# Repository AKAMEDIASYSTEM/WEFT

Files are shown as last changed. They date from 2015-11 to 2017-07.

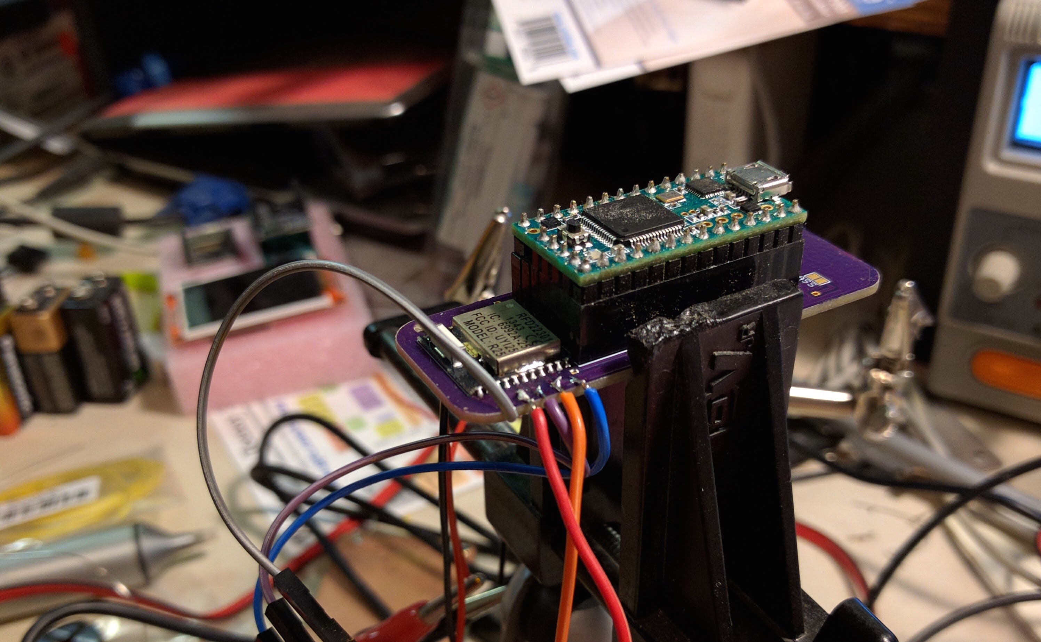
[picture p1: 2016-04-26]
WEFT-photos/electrovibration-experiments4.jpg

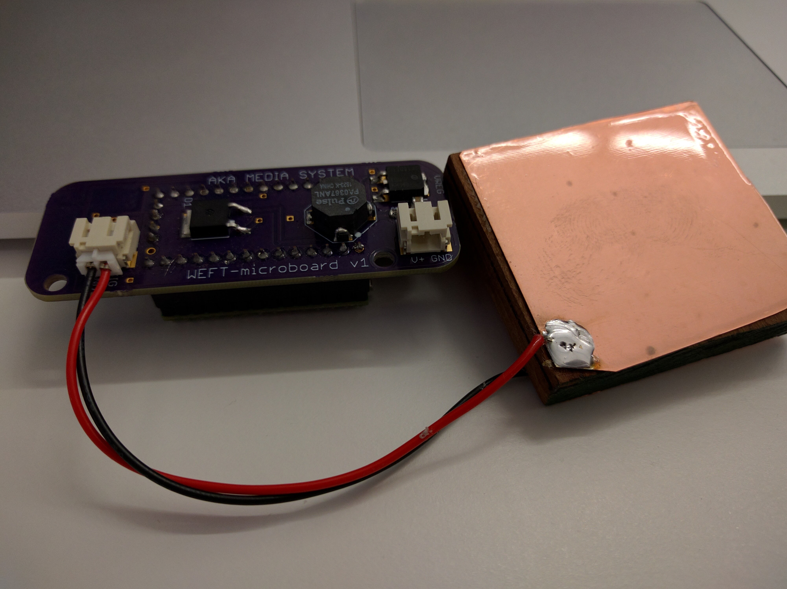
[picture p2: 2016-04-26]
WEFT-photos/electrovibration-experiments5.jpg

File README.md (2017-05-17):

# WEFT
#### Experiments in electrovibration interaction strategies, inspired by Disney Research papers "Tesla Touch" and "Revel"

Here are the papers I am trying to implement here:
http://www.ivanpoupyrev.com/e-library/2010/teslatouchUIST2010.pdf

http://www.disneyresearch.com/wp-content/uploads/REVEL.pdf

### Summary
Basically, the papers describe a way to augment surfaces with _dynamically changeable tactile properties_ - a surface can change from sticky to slippery basically at will.

### Status
This work is incomplete and ongoing - for one thing, while the circuit decribed here works, I have yet to implement current-sensing feedback as described in the papers. I'm eager to accomplish this because it allows normalization of sensation across people, skin moistures, and time.

### Why I am interested
I'm interested in experimenting with this technology as applied to various notification strategies, particularly on mobile and wearable devices.
I would like to develop interactions in which a person queries a "stack" of stuff waiting for them, rather than being interrupted by a push notification.
The appeal of this technology in this application is that it's totally silent and able to be done without interrupting the person's conversation by stealing focus.
If this technology is implemented on the back of a mobile device, for example, simply rubbing a finger along the back of the phone is all that is needed to see the magnitude of my "stack."
Of course, "stack" can be many things: number of unread emails, number of to-do items, number of places of interest very near me, and so on.

### This repository
The purpose of this repo is to make my work shareable - I had a fair amount of trouble trying to go from the research paper to a safe, working circuit, and I'm hoping to save others some work.

The circuitboard isn't what I would put onto a phone - it is instead a platform for trying out different waveforms, intensities, and so on.

The intent is that you will use the board to figure out the correct implementation details and then generate your own board with a more appropriate layout.

### Requirements
You should follow the BOM pretty precisely unless you know what you are doing. The circuit is designed to work with a 9v battery and I will be trying to allow smaller/more power supplies to work with it. The microcontroller is a Teensy 3.1

### Thanks
I'm so grateful to Disney Research, Ivan Poupyrev, Olivier Bau, and others who worked on the papers for making their work available - I never would have known aobut this cool phoneomenon without their shared work! Thanks as well to nytlabs for supporting my explorations and letting me share in kind.

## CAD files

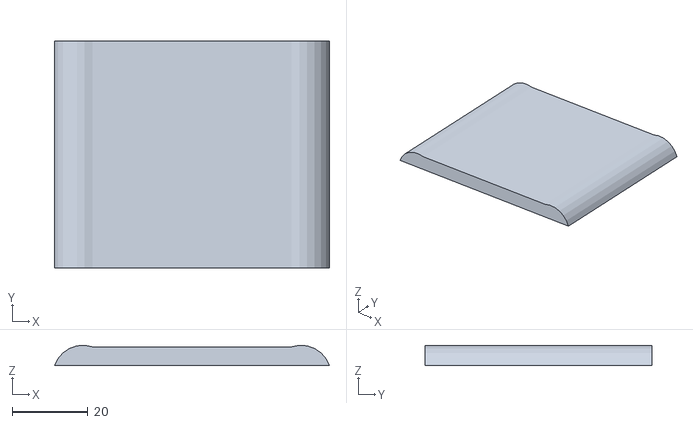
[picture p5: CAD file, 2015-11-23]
CAD/WEFT-form-test-0.stl
72.8 x 60.0 x 5.39

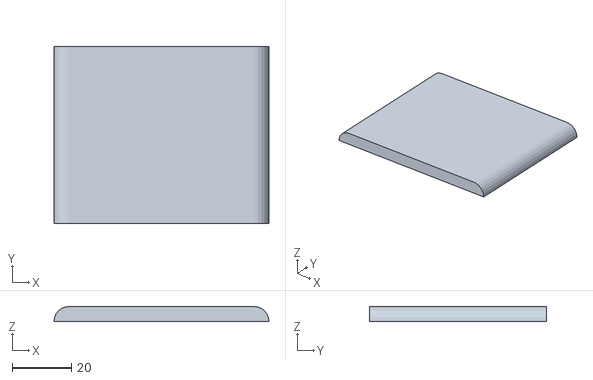
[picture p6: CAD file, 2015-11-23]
CAD/WEFT-form-test-0nobump.stl
72.8 x 60.0 x 5.00

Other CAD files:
CAD/WEFT-form-test-0.skp
CAD/WEFT-form-test-0nobump.skp
CAD/WEFT-form-test-0nobump~.skp
CAD/WEFT-form-test-0~.skp

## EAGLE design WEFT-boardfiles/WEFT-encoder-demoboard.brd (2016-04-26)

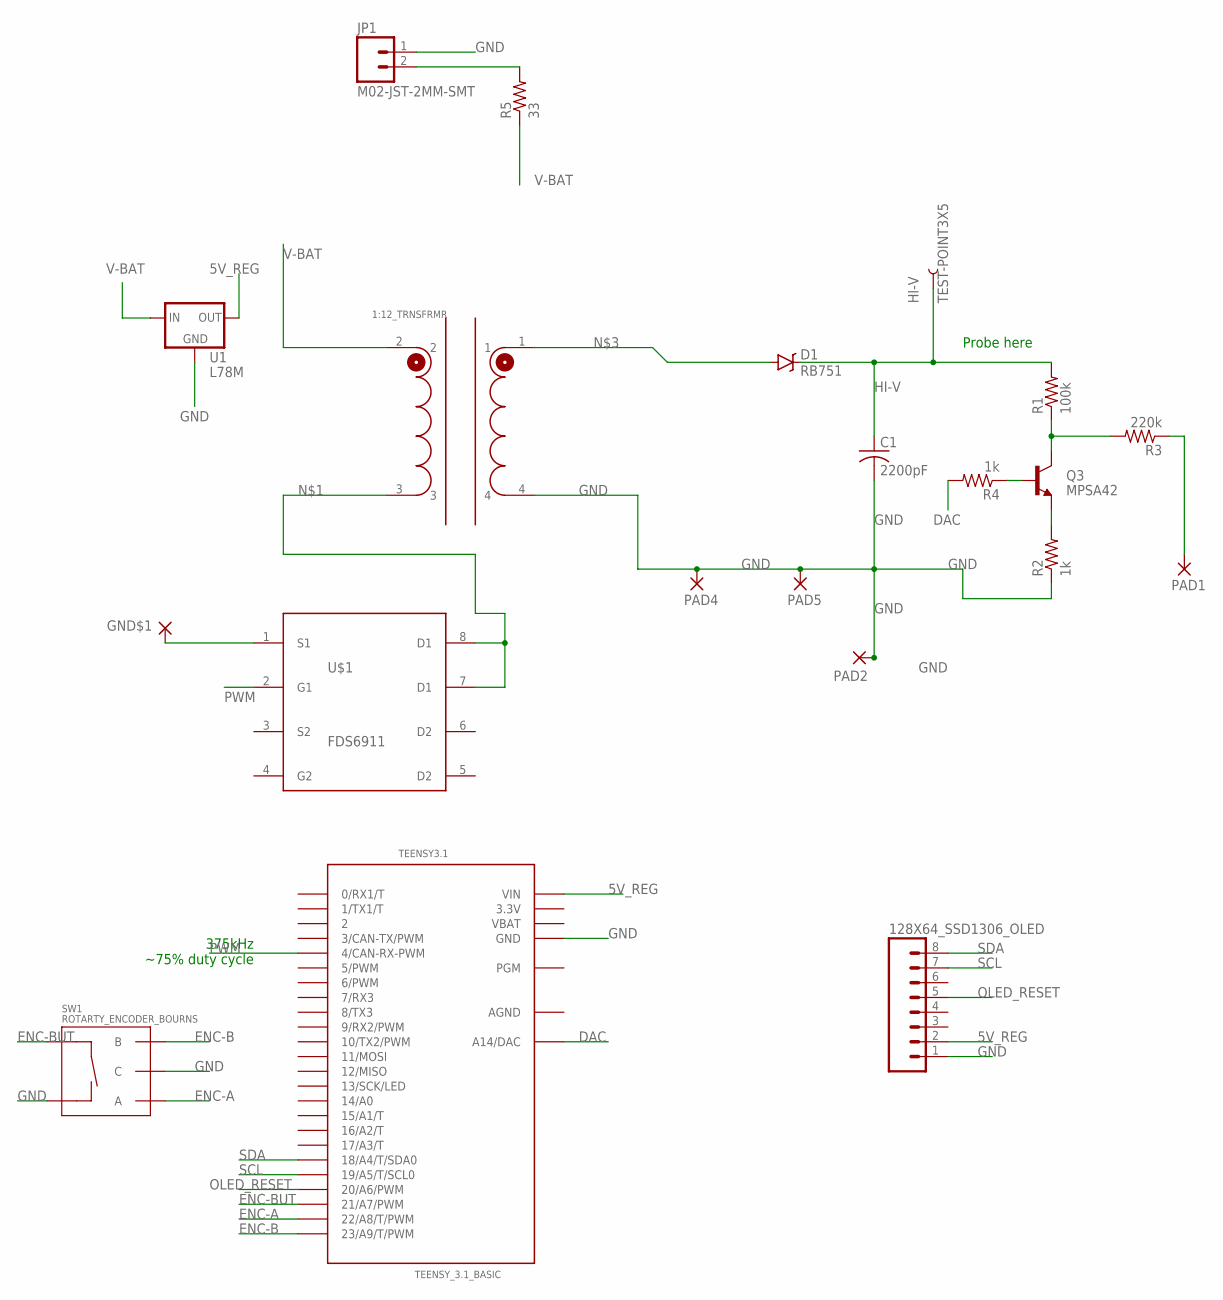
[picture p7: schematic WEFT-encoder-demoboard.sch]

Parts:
1:12_TRNSFRMR: PA0367
128X64_SSD1306_OLED: M08LOCK; 1X08_LOCK
C1: 2200pF; C1812
D1: RB751; TO263
GND$1: WIREPADSMD5-2,5; 5-2,5
HI-V: TEST-POINT3X5; PAD.03X.05
JP1: M02-JST-2MM-SMT; JST-2-SMD
PAD1, PAD2, PAD4, PAD5: WIREPADSMD5-2,5; 5-2,5
Q3: MPSA42; TO-92
R1: 100k; R2010
R2, R4: 1k; 1206
R3: 220k; R2010
R5: 33; 1206
SW1: ROTARTY_ENCODER_BOURNS; ROTARY_ENC_PLAIN_BOURNS
TEENSY3.1: TEENSY_3.1_BASIC
U1: L78M; DPAK
U$1: FDS6911; SO8

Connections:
3.3V: TEENSY3.1.3.3V
5V_REG: 128X64_SSD1306_OLED.2, TEENSY3.1.VIN, U1.3 (OUT)
AGND: TEENSY3.1.AGND
DAC: R4.2, TEENSY3.1.A14 (A14/DAC)
ENC-A: SW1.A, TEENSY3.1.22/A8 (22/A8/T/PWM)
ENC-B: SW1.B, TEENSY3.1.23/A9 (23/A9/T/PWM)
ENC-BUT: SW1.SW+, TEENSY3.1.21/A7 (21/A7/PWM)
GND: 1:12_TRNSFRMR.4, 128X64_SSD1306_OLED.1, C1.2, GND$1.1, JP1.1 (2), PAD2.1, PAD4.1, PAD5.1, R2.1, SW1.C, SW1.SW-, TEENSY3.1.GND, TEENSY3.1.GND1 (GND), U1.4 (GND), U$1.1 (S1)
HI-V: C1.1, D1.1 (C), HI-V.P$1, R1.2
unnamed: 1:12_TRNSFRMR.3, U$1.7 (D1), U$1.8 (D1)
unnamed: 1:12_TRNSFRMR.1, D1.2 (A)
unnamed: JP1.2 (1), R5.2
unnamed: Q3.1 (C), R1.1, R3.2
unnamed: Q3.3 (E), R2.2
unnamed: Q3.2 (B), R4.1
OLED_RESET: 128X64_SSD1306_OLED.5, TEENSY3.1.20/A6 (20/A6/PWM)
PAD: PAD1.1, R3.1
PWM: TEENSY3.1.4 (4/CAN-RX-PWM), U$1.2 (G1)
SCL: 128X64_SSD1306_OLED.7, TEENSY3.1.19/A5 (19/A5/T/SCL0)
SDA: 128X64_SSD1306_OLED.8, TEENSY3.1.18/A4 (18/A4/T/SDA0)
V-BAT: 1:12_TRNSFRMR.2, R5.1, U1.1 (IN)
VBAT: TEENSY3.1.VBAT

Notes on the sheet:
Probe here
375kHz ~75% duty cycle

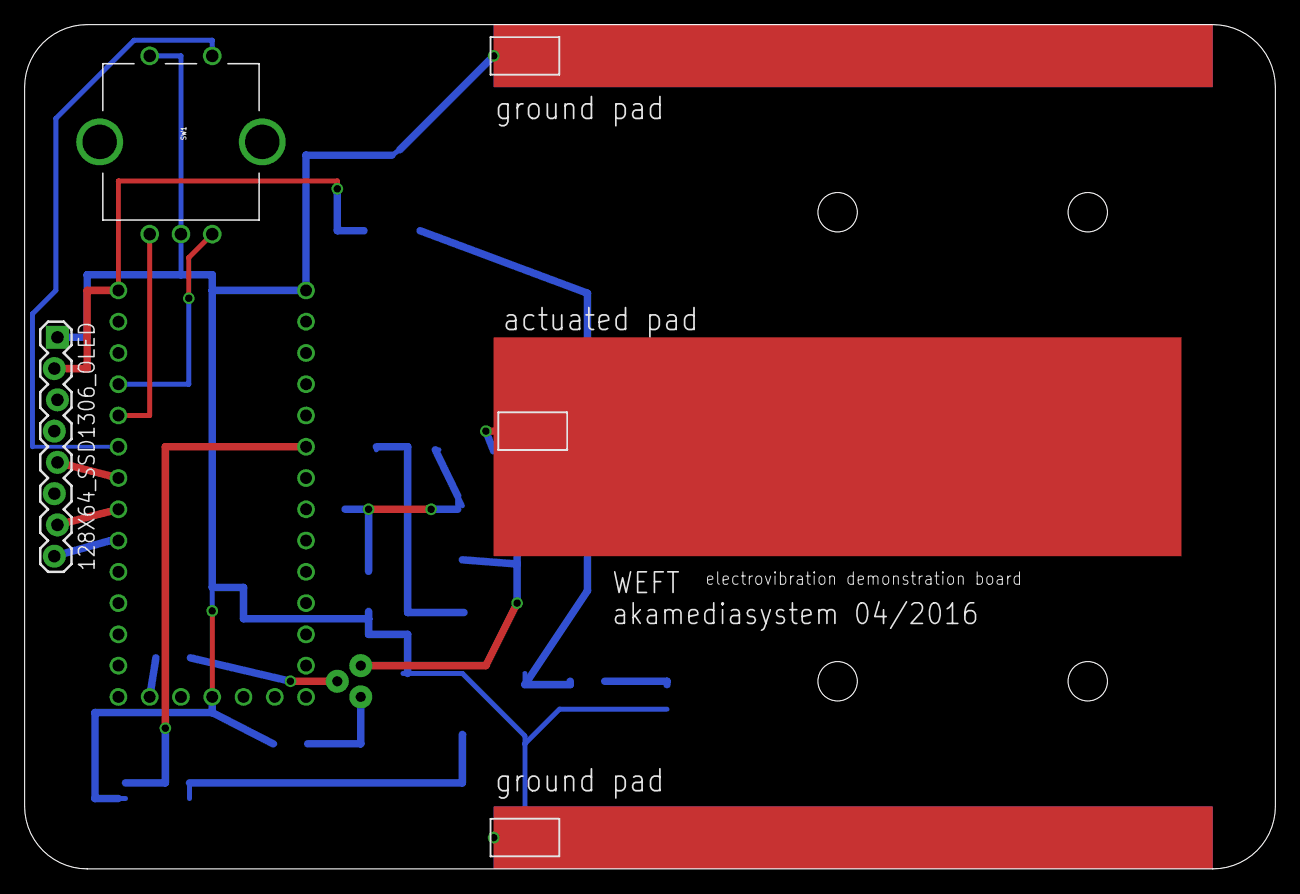
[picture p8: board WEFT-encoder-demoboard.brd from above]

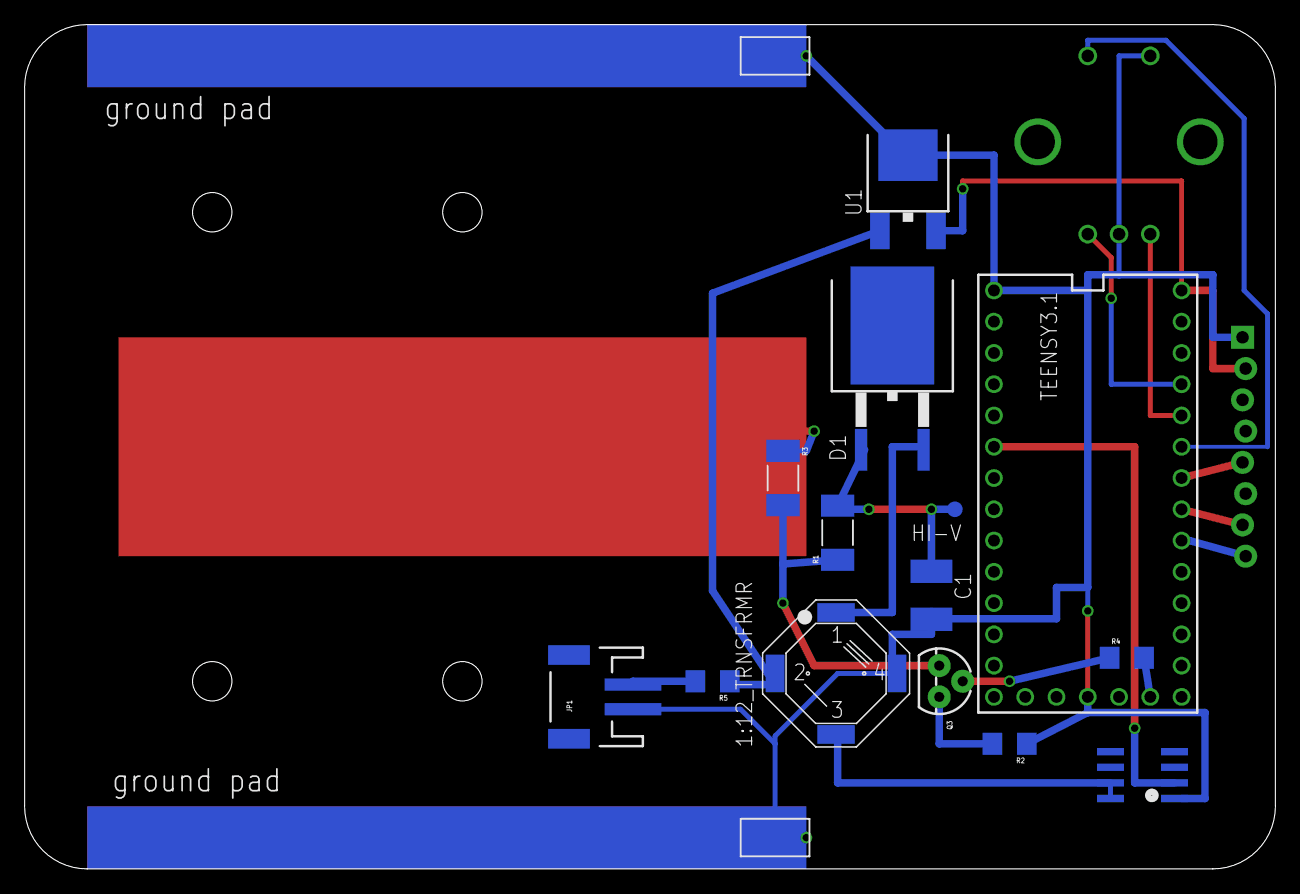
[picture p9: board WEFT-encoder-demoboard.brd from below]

Board: 2 copper layers, 101.6 x 68.6 mm, 21 parts (16 on the bottom side), 19 nets.

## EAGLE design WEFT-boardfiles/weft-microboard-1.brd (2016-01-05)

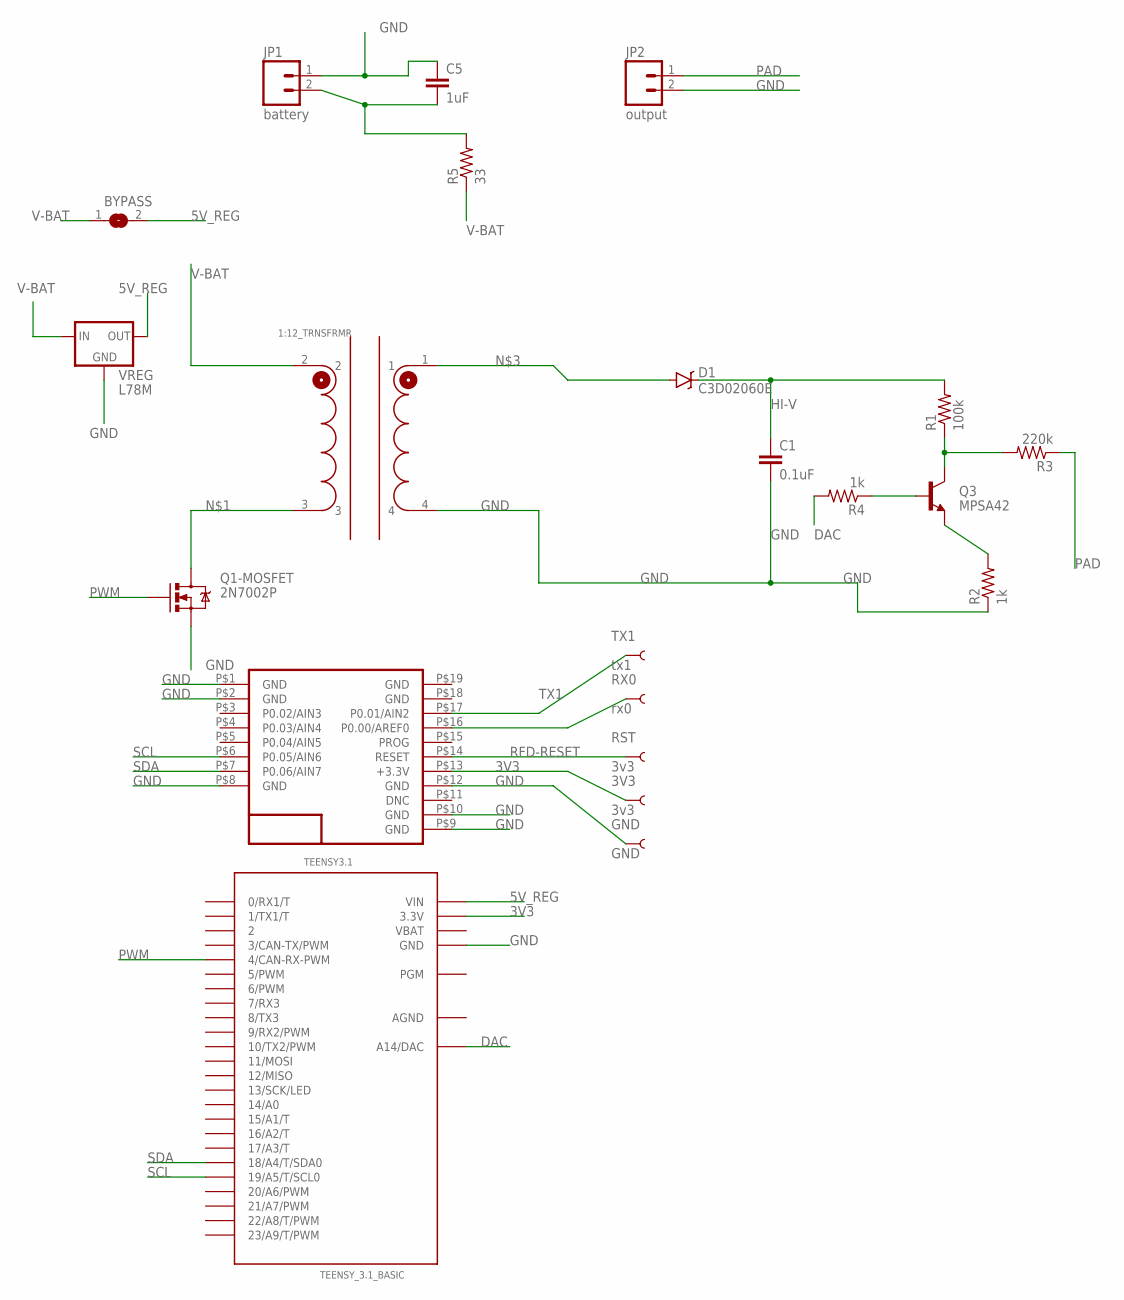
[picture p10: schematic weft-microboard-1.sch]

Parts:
1:12_TRNSFRMR: PA0367
3V3: 3v3; PAD.03X.03
BYPASS: SJ
C1: 0.1uF; 0805
C5: 1uF; 0805
D1: C3D02060E; TO252
GND: GND; PAD.03X.03
JP1: battery; JST-2-SMD
JP2: output; JST-2-SMD
Q1-MOSFET: 2N7002P; SOT23-3
Q3: MPSA42; SOT23-3
R1: 100k; 1206
R2, R4: 1k; 0805
R3: 220k; 1206
R5: 33; 0805
RFDUINO: RFD22301; RFD21733
RST: 3v3; PAD.03X.03
RX0: rx0; PAD.03X.03
TEENSY3.1: TEENSY_3.1_BASIC
TX1: tx1; PAD.03X.03
VREG: L78M; DPAK

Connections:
3V3: 3V3.P$1, RFDUINO.P$13 (+3.3V), TEENSY3.1.3.3V, TEENSY3.1.3.3V1 (3.3V)
5V_REG: BYPASS.2, TEENSY3.1.VIN, VREG.3 (OUT)
AGND: TEENSY3.1.AGND
DAC: R4.2, TEENSY3.1.A14 (A14/DAC)
EMIT: Q3.2 (E), R2.2
GND: 1:12_TRNSFRMR.4, C1.2, C5.1, GND.P$1, JP1.1 (2), JP2.2 (1), Q1-MOSFET.2 (S), R2.1, RFDUINO.P$1 (GND), RFDUINO.P$2 (GND), RFDUINO.P$8 (GND), RFDUINO.P$9 (GND), RFDUINO.P$10 (GND), RFDUINO.P$12 (GND), TEENSY3.1.GND, TEENSY3.1.GND1 (GND), VREG.4 (GND)
HI-V: C1.1, D1.1 (C), R1.2
unnamed: 1:12_TRNSFRMR.3, Q1-MOSFET.3 (D)
unnamed: RFDUINO.P$16 (P0.00/AREF0), RX0.P$1
unnamed: 1:12_TRNSFRMR.1, D1.2 (A)
unnamed: C5.2, JP1.2 (1), R5.2
unnamed: Q3.3 (C), R1.1, R3.2
unnamed: Q3.1 (B), R4.1
PAD: JP2.1 (2), R3.1
PWM: Q1-MOSFET.1 (G), TEENSY3.1.4 (4/CAN-RX-PWM)
RFD-RESET: RFDUINO.P$14 (RESET), RST.P$1
SCL: RFDUINO.P$6 (P0.05/AIN6), TEENSY3.1.19/A5 (19/A5/T/SCL0)
SDA: RFDUINO.P$7 (P0.06/AIN7), TEENSY3.1.18/A4 (18/A4/T/SDA0)
TX1: RFDUINO.P$17 (P0.01/AIN2), TX1.P$1
V-BAT: 1:12_TRNSFRMR.2, BYPASS.1, R5.1, VREG.1 (IN)
VBAT: TEENSY3.1.VBAT

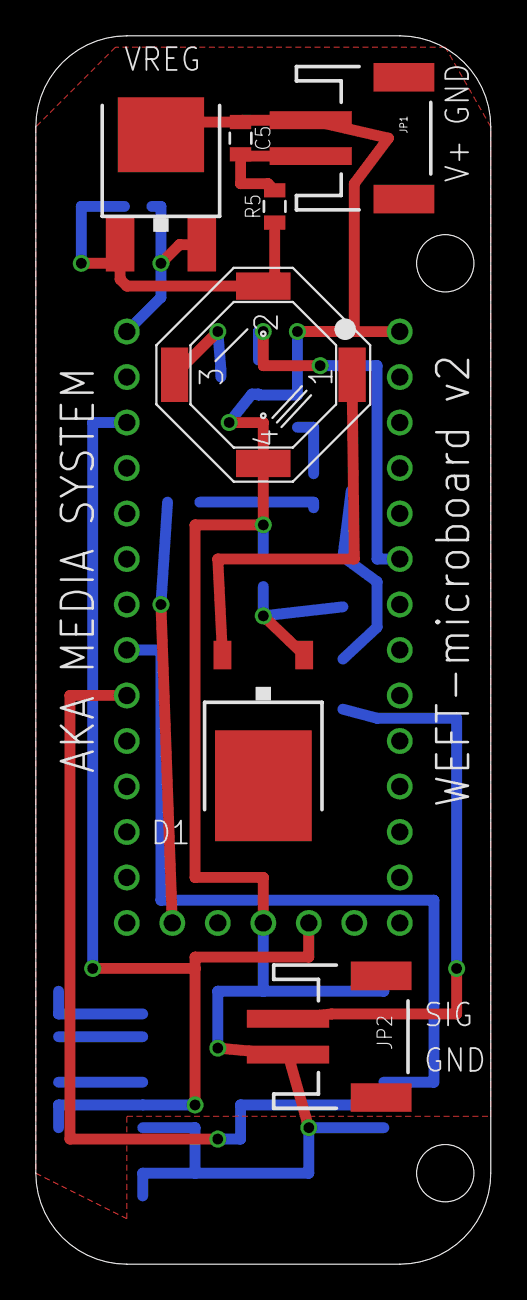
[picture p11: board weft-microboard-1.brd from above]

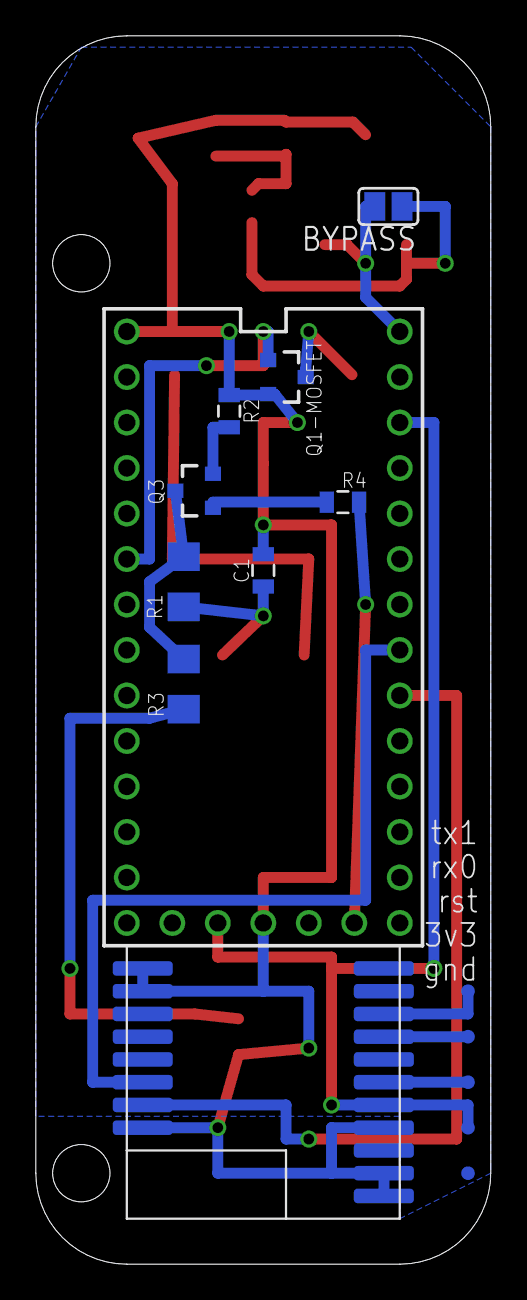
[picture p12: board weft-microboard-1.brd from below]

Board: 2 copper layers, 25.4 x 68.6 mm, 22 parts (15 on the bottom side), 19 nets.

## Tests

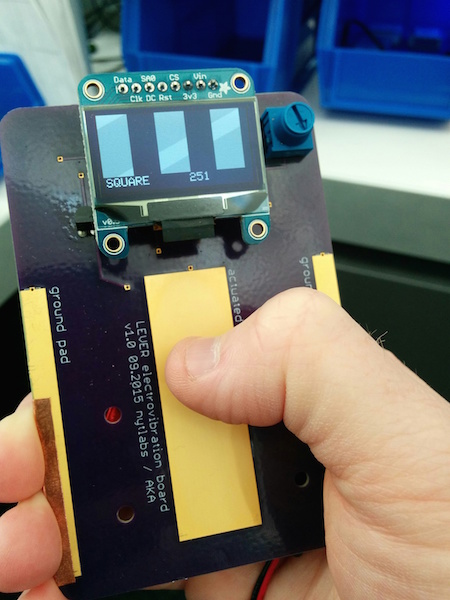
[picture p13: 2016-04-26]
WEFT-photos/electrovibration-experiments1.jpg

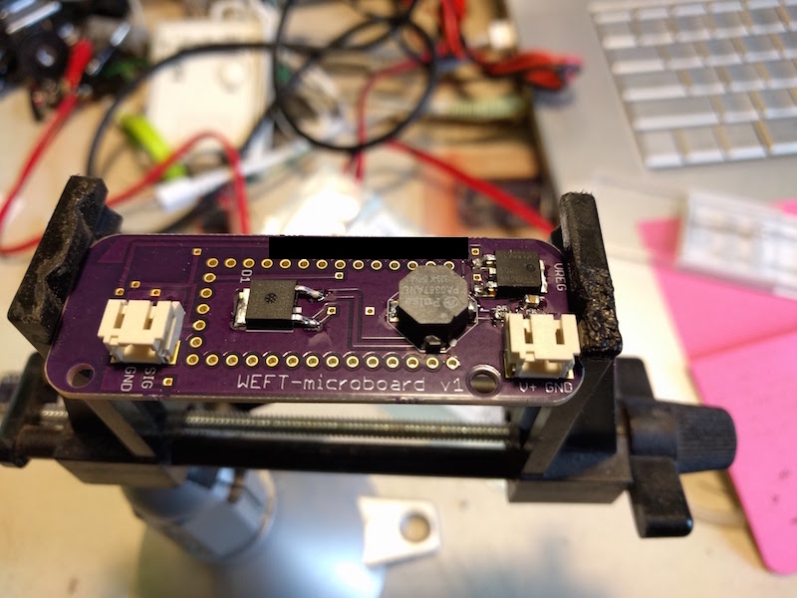
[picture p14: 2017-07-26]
WEFT-photos/electrovibration-experiments2.jpg

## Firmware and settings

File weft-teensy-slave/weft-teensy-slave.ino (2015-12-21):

// 
/*
// WEFT driver for implementation of REVEL and TeslaTouch papers by Disney Research
// for teensy 3.1
// Digital pin 4 sends hi-freq PWM (altered to send at 375kHz) to a boost converter circuit
// Analog pin 14 (it's a real DAC on the teensy 3.1) sends variable-freq sine wave to a hi-voltage transistor circuit
// that modulates the boosted supply voltage
// freqPot on pin A7 sets the signal frequency
// SDA on pin A4
// SCL on pin A5

// TODO: implement goal-seeking feedback to keep constant current despite changing impedances
// TODO: figure out where in the circuit the current-sensing occurs (pretty sure we're measuring voltage drop across precision resistor?)

//  phase = phase + 0.2; // about 600Hz
//  phase = phase + 0.05; // about 150Hz
//  phase = phase + 0.025; // about 75Hz
*/

#include <SPI.h>
#include <Wire.h>

#define pwmOut 4
#define LED 13
#define SINE 0
#define SQUARE 1
#define SAW_DESC 2
#define SAW_ASC 3
#define NOISE 4

#define waveMax 4
#define waveMin 0

float minFreq = 0.016 * 1000.0; // 0.0125 is too low for some people to feel, trying 0.016 now
float maxFreq = 0.4 * 1000.0;

float minDuty = 0.3;
float maxDuty = 0.95;
float dutyCycle = 0.3;

float minAmpl = 0.0;
float maxAmpl = 2000.0;

float DACamplitude = 2000.0;
int waveType = 1; // sine, square (default), saw descending, saw ascending, noise

float phase = 0.01;
float twopi = 3.14159 * 2;
float phaseOffset = 10; //just an initial condition, this used to be 0.05

void setup() {
  // 0 - 4095 pwm values if res set to 12-bit
  Wire.begin(8);
  Wire.onReceive(receiveEvent);
  analogWriteResolution(12);
  analogWriteFrequency(pwmOut, 375000);
  pinMode(pwmOut, OUTPUT);
  pinMode(LED, OUTPUT);
  digitalWrite(LED,HIGH);

}

void loop() {

  analogWrite(pwmOut, int(4096 * dutyCycle));

  float DACval = 0;
  phase = phase + (phaseOffset / 1000.0);
  if (phase >= twopi) {
    phase = 0;
  }

  switch (waveType) {
    case SINE:
      DACval = sin(phase) * DACamplitude + 2050.0;
      // 2050.0 is DC offset?
      break;
    case SQUARE:
      // if phase > pi then 1 else 0
      (phase > twopi / 2) ? (DACval = (DACamplitude / maxAmpl) * 4095.0) : (DACval = 0.0);
      break;
    case SAW_DESC:
      // phase itself is linearly ramping
      DACval = floatmap(phase, 0, twopi, 0.0, 1.0) * (DACamplitude / maxAmpl) * 4095.0;
      break;
    case SAW_ASC:
      // phase itself is linearly ramping
      DACval = floatmap(phase, 0, twopi, 1.0, 0.0) * (DACamplitude / maxAmpl) * 4095.0;
      break;
    case NOISE:
      (random(0, 9) > 4.5) ? (DACval = (DACamplitude / maxAmpl) * 4095.0) : (DACval = 0.0);
      break;
    default:
      DACval = sin(phase) * DACamplitude + 2050.0;
      break;
  }

  DACval = 4095.0 - DACval;
  analogWrite(A14, (int)DACval);

}

// native map func uses int math
float floatmap(float x, float in_min, float in_max, float out_min, float out_max)
{
  return (x - in_min) * (out_max - out_min) / (in_max - in_min) + out_min;
}

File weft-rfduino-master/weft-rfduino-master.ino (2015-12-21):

#include <Wire.h>
#define TEENSY_ADDR 8

/*
The sketch is an empty template for Bluetooth Low Energy 4.
Simply remove what you dont need, and fill in the rest.
*/

/*
 Copyright (c) 2014 OpenSourceRF.com.  All right reserved.

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
 THE SOFTWARE IS PROVIDED "AS IS", WITHOUT WARRANTY OF ANY KIND,
 EXPRESS OR IMPLIED, INCLUDING BUT NOT LIMITED TO THE WARRANTIES OF
 MERCHANTABILITY, FITNESS FOR A PARTICULAR PURPOSE AND NONINFRINGEMENT.
 IN NO EVENT SHALL THE AUTHORS OR COPYRIGHT HOLDERS BE LIABLE FOR ANY
 CLAIM, DAMAGES OR OTHER LIABILITY, WHETHER IN AN ACTION OF CONTRACT,
 TORT OR OTHERWISE, ARISING FROM, OUT OF OR IN CONNECTION WITH THE
 SOFTWARE OR THE USE OR OTHER DEALINGS IN THE SOFTWARE.
*/

/*
 * This is dumb firmware that just relays BLE commands from the RFduino module to the Teensy over i2c
 * 
 */

#include <RFduinoBLE.h>

void setup()
{
  Wire.begin();
  RFduinoBLE.deviceName = "WEFT-c";
  RFduinoBLE.advertisementData = "HI-WEFT";
  RFduinoBLE.advertisementInterval = MILLISECONDS(300);
  RFduinoBLE.txPowerLevel = -20;  // (-20dbM to +4 dBm)

  // start the BLE stack
  RFduinoBLE.begin();
//  Wire.beginTransmission(8);
//  Wire.write(0);
//  Wire.write(255);
//  Wire.endTransmission();
//  RFduinoBLE.send('Z');
  Serial.begin(9600);
  Serial.print("i am awake");
}

void loop()
{
  // switch to lower power mode
  //  RFduino_ULPDelay(INFINITE);

  // to send one char
  // RFduinoBLE.send((char)temp);

  // to send multiple chars
  // RFduinBLE.send(&data, len);
}

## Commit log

2015-11-15 first commit to new repo
    [LEVER-board-production-0 (SENT to OSHPark).brd, LEVER-board-production-0 (SENT to OSHPark).sch, weft-microboard-0.brd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]
2015-11-23 cleanup teensy slave code, prepare to add android app to repo
2015-11-23 adding CAD and android files, not much CAD yet
    [WEFT-form-test-0.skp, WEFT-form-test-0.stl, WEFT-form-test-0nobump.skp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]
2015-11-23 un-screwed the android code after dropbox marked all my work as 'conflicted'. Now able to connect to WEFT and use UI elements to alter signal properties
2015-12-13 rev of weftboard and tweak firmware
    [weft-microboard-1.brd, weft-microboard-1.sch]
2016-01-05 small changes
    [weft-microboard-1.brd]
2016-01-12 simplifying this app for testing with hobby board
2016-04-26 adding an encoder-ready demo board, not yet completed, and also adding photos
    [WEFT-encoder-demoboard.brd, WEFT-encoder-demoboard.sch]

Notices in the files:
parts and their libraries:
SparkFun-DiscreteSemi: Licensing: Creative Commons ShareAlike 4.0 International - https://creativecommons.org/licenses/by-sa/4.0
